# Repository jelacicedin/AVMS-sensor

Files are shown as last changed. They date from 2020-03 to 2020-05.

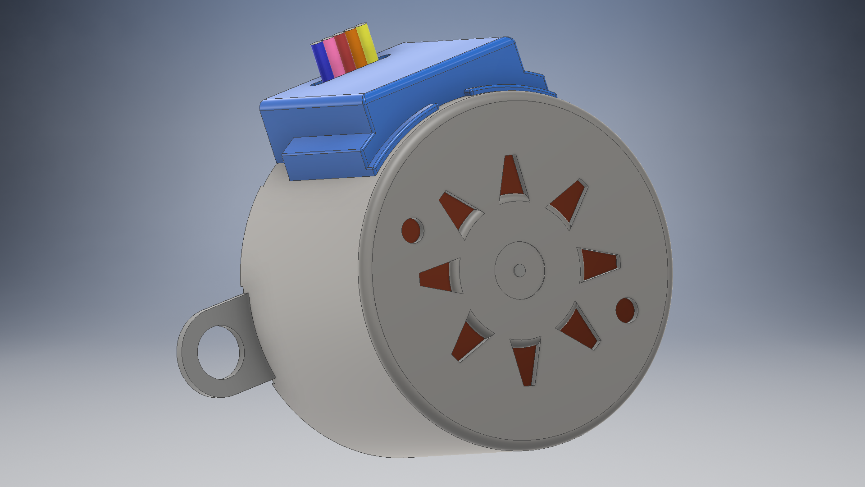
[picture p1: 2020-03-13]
Non printed/Images/28BYJ-48-stepper_02.png

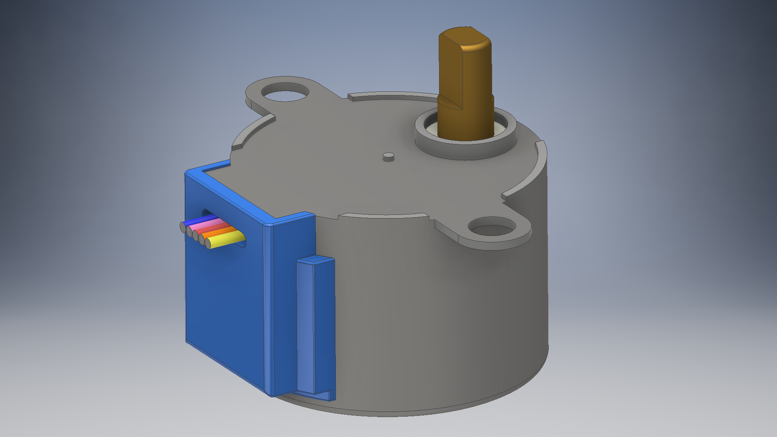
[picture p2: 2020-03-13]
Non printed/Images/28BYJ-48-stepper_03.png

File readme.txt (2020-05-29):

#LIDAR-app

For running the final version of the application, just run LIDAR-app.exe shortcut

The commands it sends to the arduino are of the form _._
where the first _ can be either "Azimuth" (which means the base motor) or "Elevation" (which means the sensor motor). 
The second _ is the int value of the angle (in degrees, int!) that the chosen motor needs to achieve.

The data it should receive is just ints for the distance. It is assumed that the motors will "obey" the commands given by the app and 
that just the distance data is necessary. I don't know yet what the best units are, but I will let you see that on the Arduino side :D

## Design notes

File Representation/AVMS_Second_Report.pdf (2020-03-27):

# AVMS Porocilo o delu, 27. marec 2020 ˇ

1. Erik Plesko | 2. Edin Jela ˇ | ciˇ c´

Povzetek—Ta clanek opisuje dosedanji potek dela sistema ˇ LIDAR senzorjev, ki je bilo jedro nasega dela na predmetu ˇ AVMS. Opisana je uporabljena oprema, nacela in specifikacije ˇ
senzorja ter zacetna programska re ˇ | sitev uporabni ˇ | skega vmesnika ˇ
za komunikacijo, upravljanje in vizualizacijo prostora, ki ga senzor zajema. Opisano je tudi prihodnje delo na tem sistemu.
I. SPLOSNI OPIS NAREJENEGA DELA ˇ
Odlocili smo se predvsem za fizi ˇ | | cno obliko sistema, kar ˇ
zadeva 3D modeliranje in integracijo senzorjev. Nato je bilo narejeno 3D modeliranje sistema znotraj programa Autodesk
Inventor, pri cemer smo upo ˇ | stevali na ˇ | crtovanje gibanja, dimen- ˇ
zije senzorjev in koracne motorje, ki bi premikali podlago in ˇ pritrdili senzor. Nato so potrebni deli 3D natisnjeni in sistem sestavljen, kot je na sliki 6. Naslednji korak je bil ustvarjanje uporabniskega vmesnika, kot je na sliki 3, ki bi prav tako ˇ izvajal komunikacijo, upravljanje in vizualizacijo. Prva dva koraka sta resena. ˇ

II. UPORABLJENA OPREMA

Merilni sistem je preko USB vodila povezan z osebnim racunalnikom. Za vodenje merilnega sistema sva uporabila ˇ mikrokrmilnik Arduino Nano. Za krmilnjenje koracnih motor- ˇ jev 28BYJ-48 sva uporabila krmilnik ULN2003. Za merjenje razdalje pa sva uporabila merilnik VL53L0X proizvajalca Pololu. Mikrokrmilnik podatke o legi motorjev in merjeni
razdalji posilja na ra ˇ | cunalnik. ˇ

III. STROJNA OPREMA

Merilni sistem je prikazan na sliki 6. Sistem je poleg
USB prikljucitve za komunikacijo z ra ˇ | cunalnikom in napajanje ˇ
mikrokrmilnika, potrebno dodatno napajati z 5 V zaradi motorjev. Za to v eksperimentalni fazi uporabljava napajalnik iz
starega osebnega racunalnika. V prihodnje oziroma v kon ˇ | cnem ˇ
produktu bo za to uporabljen bolj preprost in prenosljiv napajalnik.
Komponente se v trenutni fazi povezano z uporabo ”breadboarda”in ”jumper wires”ter izpostavljene. V prihodnje jih
namerava skriti v nekaksno ohi ˇ | sje, ki bo najbr ˇ | z pod trenutnim ˇ
sistemom.
Ohisje in nosilni elementi so 3D natisnjeni iz plastike. Na ˇ sliki 1 je CAD model sistema. Izkoristila sva svobodo pri nacrtovanju, ki jo nudi 3D tiskanje, in mehanizem naredila ˇ sestavljiv brez potrebe po vijakih ali lepilu.

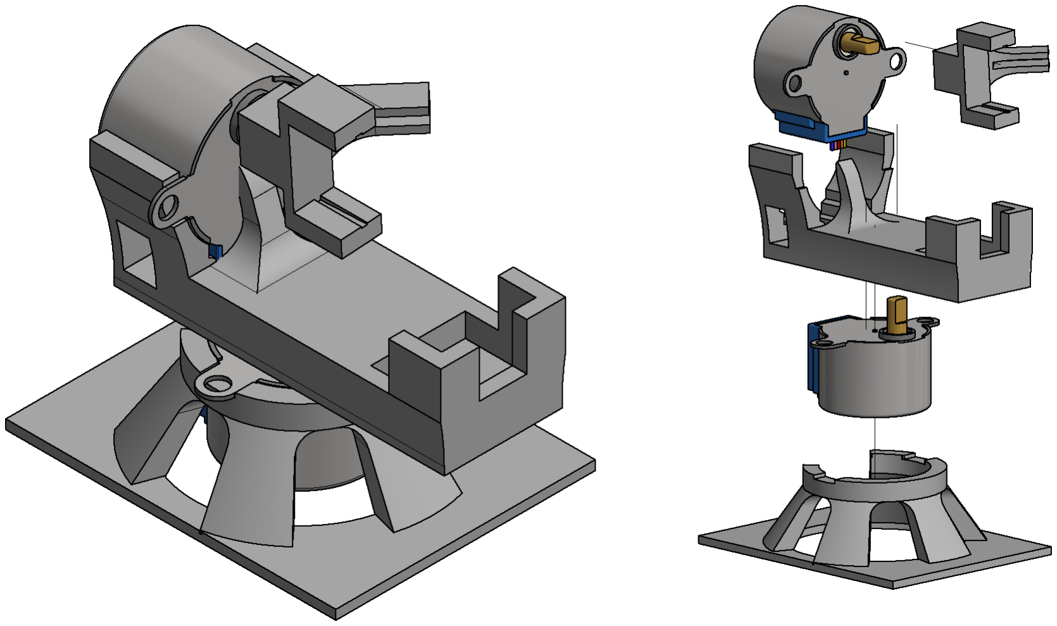
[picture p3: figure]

Slika 1. CAD model narisan v programu Autodesk Inventor. (levo) Sestavljen model brez senzorja. (desno) Eksplozijska slika sestavljanja sistema.

IV. PROGRAMSKA OPREMA

A. Mikrokrmilnik
Na mikrokrmilniku poteka program ki skrbi za usmerjanje merilnika razdalje in zajem podatkov o razdalji. Premikanje
motorjev poteka odprto zancno. Ker gre za kora ˇ | cne motorje ˇ
je informacija o zeljenem relativnem premiku tudi informacija ˇ o dejanskem premiku. Dokler ne pride do preskakovanja ali zdrsa. Glede na relativno lahko breme naju to ne skrbi prevec.ˇ
Najvecji potencialni vir ne ˇ | zeljenih obremenitev so kabli. ˇ
Sistem nima nikakrsnega na ˇ | cina za meritev pozicije. Preden ˇ
ga prizgemo je potrebno ”na roke”poskrbeti, da so motorji v ˇ
zacetni legi. V prihodnje bova sistemu dodala kon ˇ | cna stikala. ˇ
Tako se bo sistem ob zagonu sam postavil v zacetno lego. ˇ
Sistem omogoca dva na ˇ | cina delovanja. Prvi je na ˇ | cin skenira- ˇ
nja. Ko mikrokrmilnik iz racunalnika dobi dolo ˇ | cen ukaz za ˇ | cne ˇ
z skeniranjem. To poteka tako, da se sistem po inkrementih premika v obeh oseh. Vsako meritev pa ob zajemu poslje preko ˇ serijske povezave. Meritev vsebuje informacijo o poziciji obeh motorjev ter izmerjeni razdalji do tocke v katero v tem ˇ trenutku gleda merilnik razdalje.
Drugi nacin delovanja je meritev v posamezni to ˇ | cki. Pro- ˇ
gram ki tece na ra ˇ | cunalniku sporo ˇ | ci mikrokrmilniku ˇ | zeljeno ˇ
tocko, sistem se vanjo premakne in ra ˇ | cunalniku po ˇ | slje izmer- ˇ
jeno razdaljo.
Vrednosti kot so korak po eni in drugi osi za meritev pri skeniranju ter obmocje skeniranja so trenutno vgrajene ˇ v programsko kodo, ki tece na mikrokrmilniku. V prihodnje ˇ bova nadzor teh vrednosti implementirala preko graficnega ˇ vmesnika na racunalniku. ˇ
B. Vizualizacija in vmesnik
Uporabniski vmesnik (slika 3) je programiran v ˇ | | | C# znotraj
okolja Visual Studio. Opremljen je z moznostjo konfiguriranja ˇ in testiranja komunikacije na PC - Arduino liniji, kot je prika-
zano na sliki 4. Uporabniski vmesnik ima tudi dve mo ˇ | znosti ˇ
za delovanje, samodejno zajemanje, pri cemer motorji obidejo ˇ
sfericni prostor nad osnovo senzorja, in pa ro ˇ | cno nastavljanje ˇ

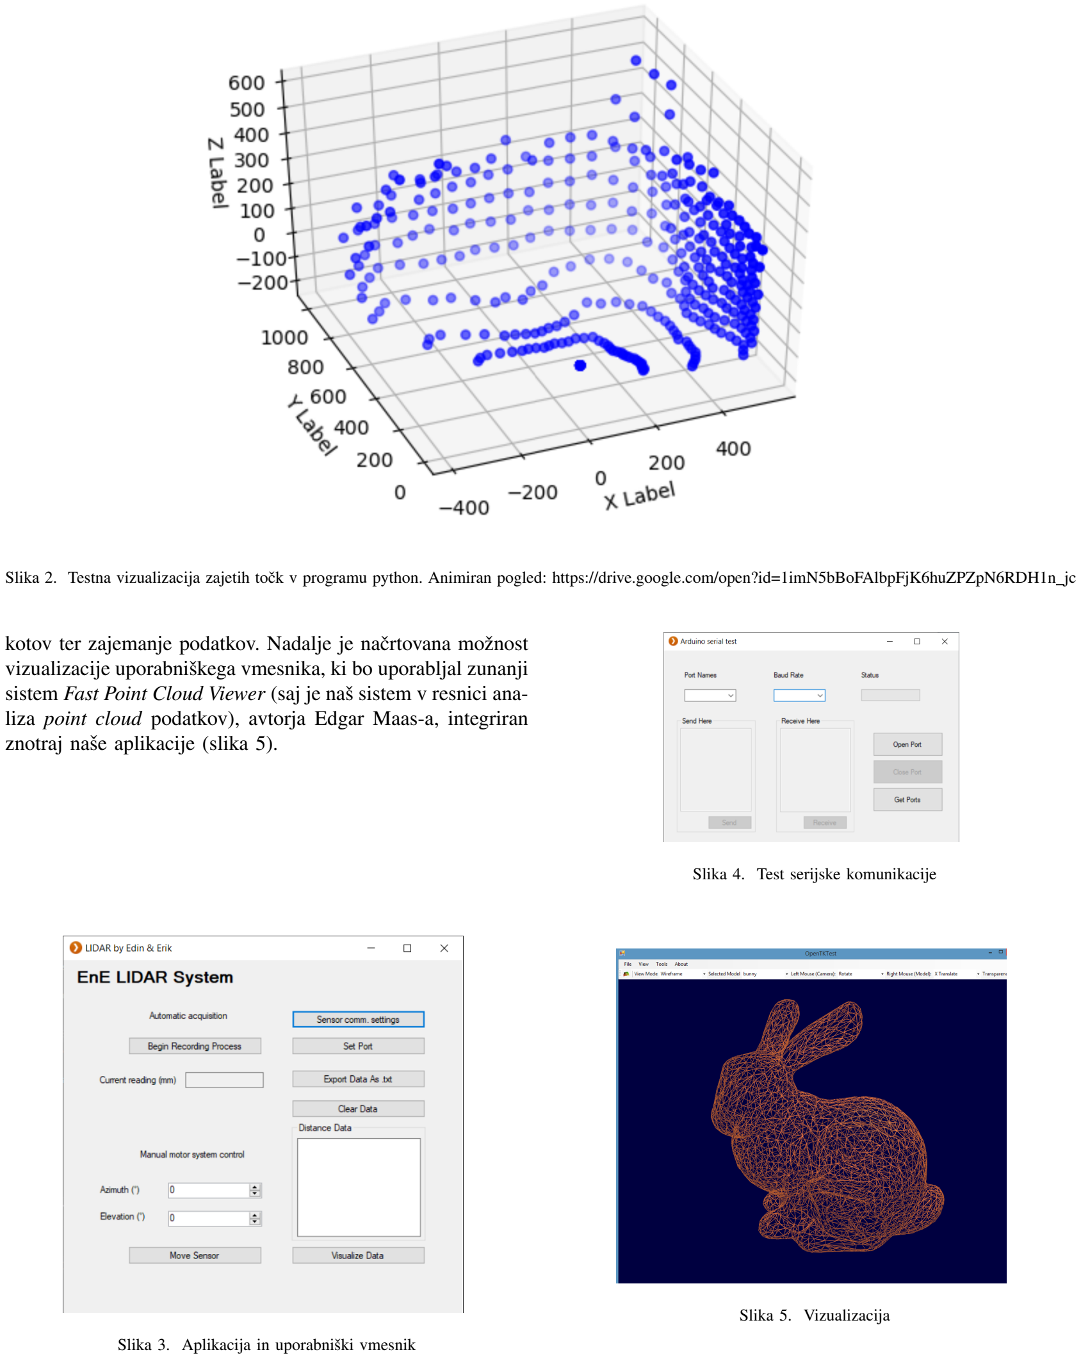
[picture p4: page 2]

Slika 2. Testna vizualizacija zajetih tock v programu python. Animiran pogled: https://drive.google.com/open?id=1imN5bBoFAlbpFjK6huZPZpN6RDH1n ˇ | jc
kotov ter zajemanje podatkov. Nadalje je nacrtovana mo ˇ | znost ˇ
vizualizacije uporabniskega vmesnika, ki bo uporabljal zunanji ˇ
sistem Fast Point Cloud Viewer (saj je nas sistem v resnici ana- ˇ liza point cloud podatkov), avtorja Edgar Maas-a, integriran znotraj nase aplikacije (slika 5). ˇ

Slika 3. Aplikacija in uporabniski vmesnik ˇ

Slika 4. Test serijske komunikacije

Slika 5. Vizualizacija

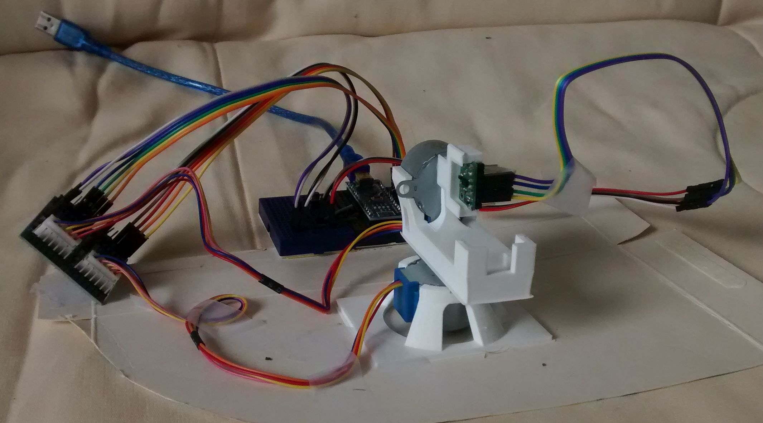
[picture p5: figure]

Slika 6. Fotografija merilnega sistema.

V. PRIHODNOST
Na podrocju strojne opreme se naredi ohi ˇ | sje v katerega se ˇ
skrije vse kar za uporabo sistema ni potrebno. Viden mora biti merilnik razdalje, USB prikljucek na mikrokrmilniku ter ˇ prikljucek za napajalni kabel. Poleg tega se najde primeren ˇ napajalnik.
Na podrocju programske opreme se nastavljanje nastavitev ˇ skeniranja premakne na racunalnik. Cilj je, da je vsa potrebna ˇ
konfiguracija mogoca iz grafi ˇ | cnega vmesnika preko serijske ˇ
povezave. Zelimo se znebiti potrebe po spreminjanju izvorne ˇ kode programa na mikrokrmilniku.

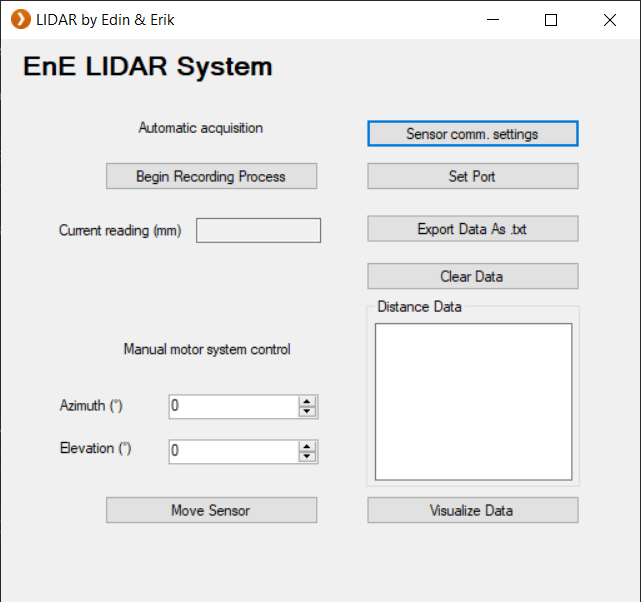
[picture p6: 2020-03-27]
Representation/app_screenshot_probably_final.png

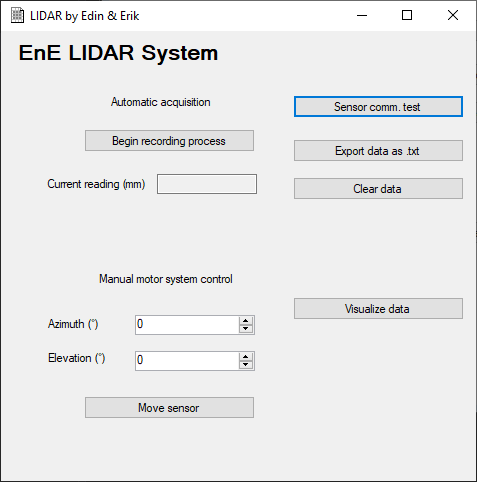
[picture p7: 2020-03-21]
Representation/app_screenshot_first_idea.png

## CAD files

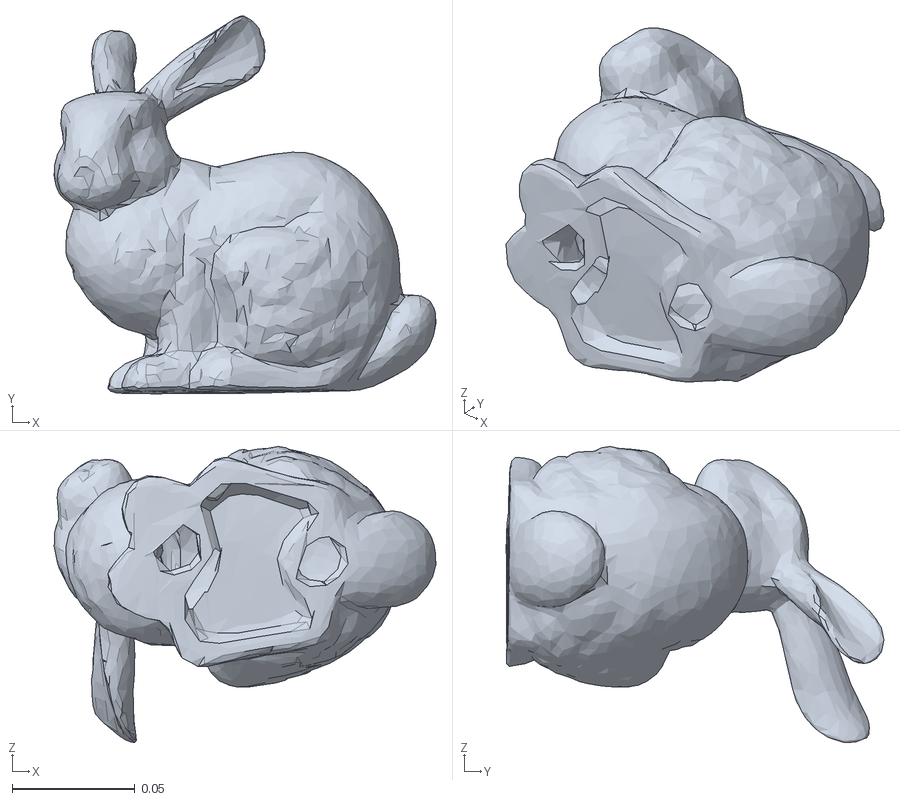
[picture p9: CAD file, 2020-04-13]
LIDAR-app/LIDAR-app/bin/Release/Models/UnitTests/bunny.obj
0.155 x 0.154 x 0.12

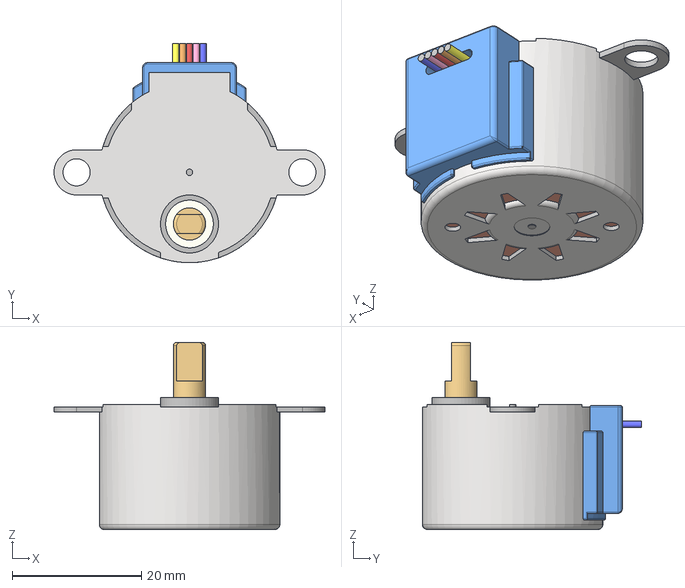
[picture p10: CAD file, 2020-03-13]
Non printed/28BYJ-48-stepper.stp
42.0 x 34.0 x 29.0 mm

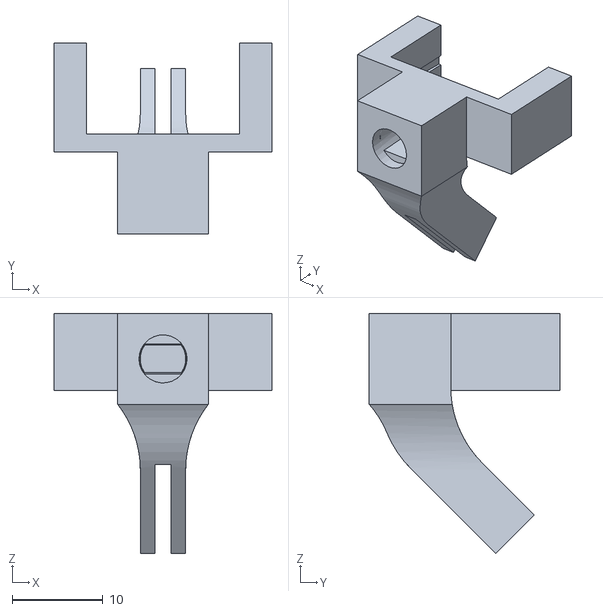
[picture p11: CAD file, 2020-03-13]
prototipV01/STL - for print/sensor holder.stl
24.0 x 21.0 x 26.4

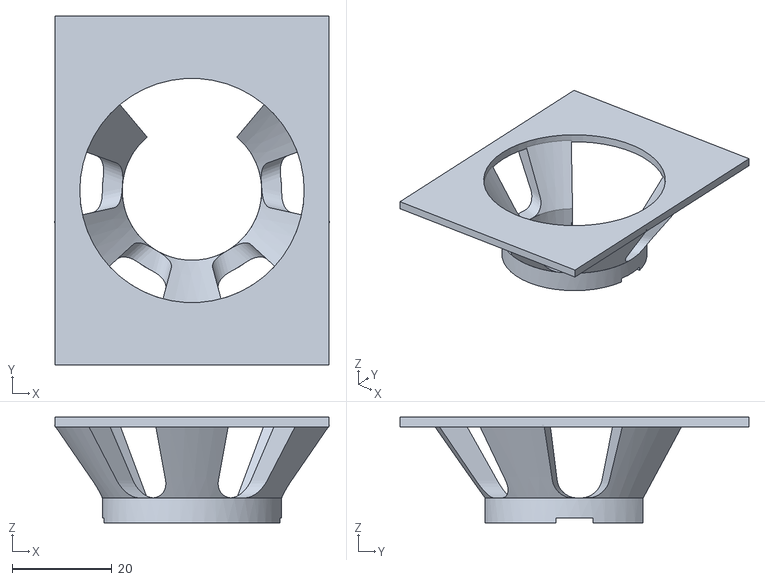
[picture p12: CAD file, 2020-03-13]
prototipV01/STL - for print/Base.stl
55.2 x 70.0 x 21.2

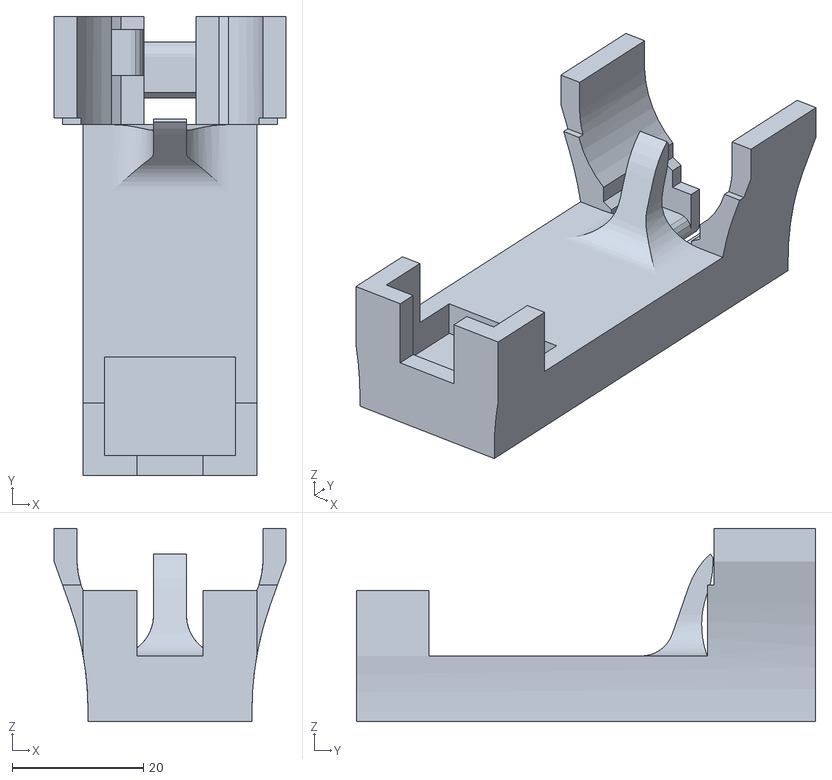
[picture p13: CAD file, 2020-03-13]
prototipV01/STL - for print/segment_1.stl
35.4 x 70.0 x 29.4

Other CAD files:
Non printed/28BYJ-48-stepper.ipt
Non printed/OldVersions/sensor holder.0001.ipt
Non printed/OldVersions/sensor holder.0004.ipt
prototipV01/Base.ipt
prototipV01/OldVersions/segment_1.0008.ipt
prototipV01/OldVersions/sestav mehanizma.0009.iam
prototipV01/segment_1.ipt
prototipV01/sensor holder.ipt
prototipV01/sestav mehanizma.iam

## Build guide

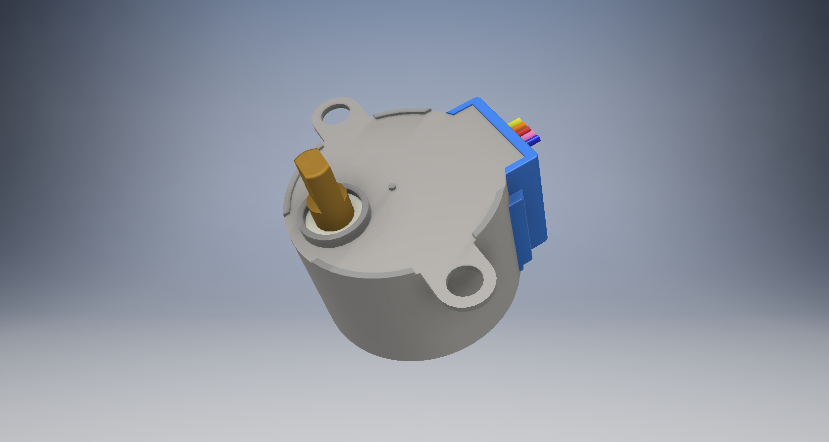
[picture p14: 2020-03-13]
Non printed/Images/28BYJ-48-stepper_01.png

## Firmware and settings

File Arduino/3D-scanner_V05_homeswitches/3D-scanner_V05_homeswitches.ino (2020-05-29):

/*
  Made by Erik (14.3.2020)

  2 DOF system for a 3D scanner 

  Equipement:
  - Arduino Nano
  - 2x (28BYJ-48 stepper motor with ULN2003 driver board)
  - VL53L0X distance sensor

  Based on:
  - Example sketch to control a 28BYJ-48 stepper motor with ULN2003 driver board and Arduino UNO. More info:
    https://www.makerguides.com/28byj-48-stepper-motor-arduino-tutorial/
  - example from Adafruit_VL53L0X.h library, with some explanation on:
    https://learn.adafruit.com/adafruit-vl53l0x-micro-lidar-distance-sensor-breakout/arduino-code
*/


/*
   Connections:

   ## VL53L0X distance sensor: ##
    Pins on VL53L0X to connect:
      VIN(5V), GND, SDA, SCL
    Arduino Nano side:
      SDA - A4
      SCL - A5

   ## 28BYJ-48 stepper motor ##
    Pins on ULN2003 driver board (for the Base motor):
      Pin 8 to IN1 on the ULN2003 driver
      Pin 9 to IN2 on the ULN2003 driver
      Pin 10 to IN3 on the ULN2003 driver
      Pin 11 to IN4 on the ULN2003 driver

    Pins on ULN2003 driver board (for the Arm motor):
      Pin 4 to IN1 on the ULN2003 driver
      Pin 5 to IN2 on the ULN2003 driver
      Pin 6 to IN3 on the ULN2003 driver
      Pin 7 to IN4 on the ULN2003 driver

*/

/*
    Versions:
      - V03: non-blocking scanning (begin with 'startscan', stop with 'stopscan')
      - V04: Elevation and Azimuth control (arm and base), help
      - V05: homeswitches 

*/




#include <Stepper.h>
#include "Adafruit_VL53L0X.h"


Adafruit_VL53L0X lox = Adafruit_VL53L0X();


// Define number of steps per rotation:
const int stepsPerRevolution = 2048;
const int stepsPerMovePhi = 20;
const int stepsPerMoveTheta = 20;

// Set the speed to 5 rpm:
char stepper_speed = 5;
  

const int phiWindow = stepsPerRevolution / 3 + stepsPerRevolution / 8 ;
const int thetaWindow = stepsPerRevolution / 8;

int absStepsBase = 0;
int absStepsArm = stepsPerRevolution/4;
bool scanActive = 0;
bool sendDistance = 0;
bool goHome = 0;

unsigned long targetStepsBase = absStepsBase; // unsigned long to not overflow degrees-to-steps computation
unsigned long targetStepsArm = absStepsArm;
bool targetingStepsActive = 0;

// Create stepper object called 'myStepper', note the pin order:
Stepper motor_base = Stepper(stepsPerRevolution, 8, 10, 9, 11);
Stepper motor_arm = Stepper(stepsPerRevolution, 4, 6, 5, 7);


// Scan "for loops" stuff:
// Loop a - outer loop (theta)
int i_a;
int loop_a_Max;
// Loop b - inner loop (phi)
int i_b;
int loop_b_Max;


// Serial communication:
bool printAll = 0; // To have all the messages printed

char incomingChar = 0;
int recievingNumber = 0;
const char incomingCommandMaxLength = 20;
char incomingCommand[incomingCommandMaxLength] = "";
int incomingCommandIndex = 0;



// Home switch pins:
const int homeSwitchBase = 2;
const int homeSwitchArm = 3;




void setup() {
  Serial.begin(9600);
  // wait until serial port opens for native USB devices
  while (! Serial) {
    delay(1);
  }

  //  Serial.println(F("System setting up..."));
  if (!lox.begin()) {
    Serial.println(F("Failed to boot VL53L0X"));
    while (1);
  }


  motor_base.setSpeed(stepper_speed);
  motor_arm.setSpeed(stepper_speed);

  // Initialize scanning loop:
  loop_a_Max = thetaWindow/stepsPerMoveTheta;
  loop_b_Max = phiWindow / stepsPerMovePhi;
  i_a = loop_a_Max;
  i_b = loop_b_Max;

  // homeswitch pins:
  pinMode(homeSwitchBase, INPUT_PULLUP);
  pinMode(homeSwitchArm, INPUT_PULLUP);
}


void loop() {





  

  // Check serial
  while (Serial.available()) {
    incomingChar = Serial.read();
    
    if (incomingChar == '\n') {
// ###################################################
// ###
// ##   Execute the commands recieved over serial
// #


// Start or Stop the scan
    if (strcmp(incomingCommand, "stopscan") == 0 || strcmp(incomingCommand, "startscan") == 0) {
      // stop scan
      // stop foor loops
      i_a = loop_a_Max;
      i_b = loop_b_Max;
      // Do stuff that need to be done at stop:
      if (printAll) Serial.println("Stopping the scan.");
      // Return motors to start position
      // Return phi to zero
      motor_base.step(-absStepsBase);
      absStepsBase += -absStepsBase;
      // Return theta to start position
      motor_arm.step(stepsPerRevolution/4 - absStepsArm);
      absStepsArm += stepsPerRevolution/4 - absStepsArm;
      scanActive = 0;
      
      if (strcmp(incomingCommand, "startscan") == 0) {
        // begin scan
        // start foor loops
        i_a = 0;
        i_b = 0;
        // Do stuff that needs to be done at start:
        if (printAll) Serial.println(F("Begining the scan."));
        // Move theta to starting position
//        motor_arm.step(-thetaWindow/2);
//        absStepsArm += -thetaWindow/2;
        scanActive = 1;
      } 
    } else if (strcmp(incomingCommand, "Azimuth") == 0) {
      if (!scanActive) {
        targetStepsBase = recievingNumber*long(stepsPerRevolution)/360;
        if (printAll) {Serial.print(F("targetStepsBase = ")); Serial.println(targetStepsBase);}
        targetingStepsActive = 1;
      } else {
        if (printAll) Serial.println(F("Custom moves are ignored when scan is in progress.")) ;
      }
    } else if (strcmp(incomingCommand, "Elevation") == 0) {
      if (!scanActive) {
        targetStepsArm = (90-recievingNumber)*long(stepsPerRevolution)/360;
        if (printAll) {Serial.print(F("targetStepsArm = ")); Serial.println(targetStepsBase);}
        targetingStepsActive = 1;
      } else {
        if (printAll) Serial.println(F("Custom moves are ignored when scan is in progress."));
      }
    } else if (strcmp(incomingCommand, "homemotors") == 0) {
      goHome = 1;
    }
    
    
    
    
    else if (strcmp(incomingCommand, "printall") == 0) {
      printAll = recievingNumber;
      Serial.println(F("printAll toggled."));
    } else if (strcmp(incomingCommand, "help") == 0) {
      Serial.println(F("Available commands:"));
      Serial.println(F("startscan, stopscan"));
      Serial.println(F("Azimuth [deg], Elevation [deg]"));
      Serial.println(F("homemotors,"));

      Serial.println(F("printall [bool], help"));
    } else {
      if (printAll) Serial.println(F("Command ignored because it was not recognized."));
    }
    


// #
// ##   Execute the commands recieved over serial
// ###
// ###################################################
      // Reset recieving buffer variables
      recievingNumber = 0;
      incomingCommandIndex = 0;
      incomingCommand[0] = '\0';
    } else {
      // Continue reading the command
      if ( ('0' <= incomingChar) && (incomingChar <= '9')  ) {
        recievingNumber = recievingNumber*10 + (incomingChar - '0');
      } else if (incomingChar == ' ' || incomingChar == '.') {
        // Ignore those characters.
      } else {
        if (incomingCommandIndex + 1 < incomingCommandMaxLength) {
          incomingCommand[incomingCommandIndex++] = incomingChar;
          incomingCommand[incomingCommandIndex] = '\0';
        } else {
          if (printAll) Serial.println(F("Recieved command string too long."));
        }
      }
    }
  } // - end of serial while


// #########################################
// Move motors to home position (base 0, arm = stepsPerRevolution/4)

  if (goHome) {
    // Home arm:
    while (digitalRead(homeSwitchArm)) {
      motor_arm.step(1);
    }
    motor_arm.step(-150);
    absStepsArm = stepsPerRevolution/4; //Now we know where the motor is

    // Home base:
    motor_base.setSpeed(2);
    while (digitalRead(homeSwitchBase)) {
      motor_base.step(-1);
    }
    motor_base.setSpeed(stepper_speed);
    motor_base.step(280);
    absStepsBase = 0;
    
    goHome = 0;
  }







// #########################################
// Moving to targeted steps:
  if (targetingStepsActive) {
    if (!scanActive) {
      // Move phi to target position
      motor_base.step(targetStepsBase - absStepsBase);
      absStepsBase += targetStepsBase - absStepsBase;
  
      // Move theta to target position
      motor_arm.step(targetStepsArm - absStepsArm);
      absStepsArm += targetStepsArm - absStepsArm;

      // raise the flag to send the distance over serial
      sendDistance = 1;
      
      // Reset targeting
      targetingStepsActive = 0;

    } else {
      if (printAll) Serial.println(F("Custom moves are ignored when scan is in progress."));
    }
  }


// #########################################
  // Measure and send distance over serial
  if (sendDistance) {
    VL53L0X_RangingMeasurementData_t measure;
    lox.rangingTest(&measure, false); // pass in 'true' to get debug data printout!
    if (measure.RangeStatus != 4) {  // phase failures have incorrect data
      if (printAll) Serial.print(F("Measured range in mm = "));
      Serial.println(measure.RangeMilliMeter);
    } else {
      Serial.println(5000);
      if (printAll) Serial.println(F("distance out of range"));
    }
    sendDistance = 0;
    
  }
  
  
  
// ###################################################
// ###
// ##   Scanning procedure (non-blocking)
// #
  if (i_a < loop_a_Max) {
    // ### Start outer Loop: ### -------------------------
    if ( (i_b == 0) || (loop_b_Max <= i_b) ) {
      // do stuff before inner loop:
        // none (just inner loop initialization)
  
      // Inner loop initialization:
      i_b = 0;
    }
    
    // ### Inner Loop: ### -------------------------
    if (i_b < loop_b_Max) {
        // loop b:
        VL53L0X_RangingMeasurementData_t measure;
        lox.rangingTest(&measure, false); // pass in 'true' to get debug data printout!
        if (measure.RangeStatus != 4) {  // phase failures have incorrect data
          Serial.print("s");
          Serial.print(measure.RangeMilliMeter);
          Serial.print("d"); 
          Serial.print(absStepsBase); Serial.print("p");
          Serial.print(absStepsArm); Serial.print("t");
          Serial.print('\n');
        } else {
          // Serial.print("2500");
          // No point to see
        }
        // Move phi
        motor_base.step(stepsPerMovePhi);
        absStepsBase += stepsPerMovePhi;

        // Inner loop mechanics:
        i_b++;
    }

    // ### Continue outer loop: ### ----------------
    if (loop_b_Max <= i_b) {
      // Return phi to zero
      motor_base.step(-absStepsBase);
      absStepsBase += -absStepsBase;
      // Move theta
      motor_arm.step(-stepsPerMoveTheta);
      absStepsArm += -stepsPerMoveTheta;


      // Outer loop mechanics
      i_a++;

      // after the last outer loop iteration (finish scan)
      if (loop_a_Max <= i_a) {
        // Scan is finished
        Serial.print("stop\n");
        
        // Return theta to start position
        motor_arm.step(stepsPerRevolution/4 - absStepsArm);
        absStepsArm += stepsPerRevolution/4 - absStepsArm;
        scanActive = 0;
      }
    } // - end of part after inner loop
  } // - end of outer loop
// #
// ##   Scanning procedure
// ###
// ###################################################



}

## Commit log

2020-03-27 Create arduino_readme.txt
    Folder for arduino source code (versions)
2020-05-01 arduino V04 - predzadnje porocilo
    Stanje programa arduina v casu oddaje predzadnjega porocila
2020-05-29 Home switches
    Added working of home switches. This is the version at the time of final report submission.
